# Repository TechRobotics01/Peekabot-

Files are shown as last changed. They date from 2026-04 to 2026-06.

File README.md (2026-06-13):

# Peekabot-
Peekabot is a esp32 based spy /surveillance camera system it is accessible from anywhere in the world (as long as it is connected to wifi) and it is accessed through telegram bot..

# REASON FOR BUILDING THIS 
why was this made you may ask well i previousely made a esp32 spy camera but it was based on wifi and it didn't have that long of a range also it was not battery operated and no custom pcb or any BMS so i made this and this project has all what the previous one lacked  
# LOGIC 
1. powers on 
2. searches for saved wifi
3. connects to wifi
4. connects to telegram bot via generated API key
5. bot starts
6. checks for incoming commands
7. returns output based on the input

# COMMANDS
1. "/start" to start the bot 
2. "/photo" to capture and send the image
3. "/flash on" to turn on the flash
4. "/flash off" to turn off the flash
5. "/quality" use this command followed by integres from 10-63 eg "/quality 20" (lower the number higher the quality)
8. "/autoflash on/off" to enable or disable the functionalty of tunring on flash automatically when taking a photo 
9. "/help" to get list of all the commands inside the bot's UI

# HARDWARE!
so this is a rough idea of what hardware will be used for this project!
1. Esp32 Ai-Thinker camera module
2. custom PCB base module with reset button and a usb port to power it easily 
3. 3d printed enclosure
4. 2x li-ion batteries

# PCB!!

so the pcb for the V1 of this project consists of 
1. IP5306 battery charging module 
2. micro usb connector 
3. battery connector
4.  header pins (to connect esp32 camera module)

the pcb has a samll form factor overall and will be powered by 2 li-ion battries which should give it a battery life of aproximately 8-12 hours which is enough for most applications furthermore you can just keep it plugged in via a micro usb port and keep it at a fixed place connect it to your wifi and not worry

Furthermore i will optimize the code so that the esp32 will go to deep sleep so that it could possibly in theory survive for months on a singular charge!! 

(update) the deepsleep is not implementable for this because deep sleep will result in turning off the wifi which will result in disconnection from the telegram api servers and the esp32 would not be able to wake up and it would remain in deep sleep
# SCHEMATICS






# 3D DESIGN!!
so the 3d design of this project is subdivided into 3 majour and minor parts 
1. the pcb enclosure case (3d part 1)
2. the pcb holder lid (3d part 2)
3. The battery holder (3d part 3)
4. 8x M2 2.2mm screws 

so basically the entire structure is made up of 3 parts one inside thich the pcb is mounted and then the lid of the same box 
then the battery are mounted under these 2 parts and this part is bigger and heavier than majority of the build...

Everything the pcb, the lid and the battery holder part are assembeled using M2 2.2mm screws which hold everything in place sturdily....

i tried to make the entire design as small ad i could but still it is bigger than expected however for the v1 of this build i just need a working prototype and i can impliment a better structure later on

peekabot_pcb_v1 v13
peekabot_pcb_v1 v13 PG2


## HOW TO ASSEMBLE IT ##
1. print all the parts in the 3D designs folder
2. get the pcb shipped from anywhere you can use PCBA but soldering everything yourself would be much cheaper
3. put all the SMD components for the pcb put them on the pcb with some solder paste and then put it on a hotplate and let the solder paste melt and all the smd components will be soldered in place
4. now connect 2 li-ion battery in series and solder the output wires and then add a male JST connector
5. now place the pcb in the middle piece 3d print and then screw it on using M2 allen screws
6. then connect the battery JST connector to the PCB
7. then put the esp32 camera on the PCb female header pins
8. now put all the parts together and screw it together with M2 2.2mm 10mm deep screws and refer to the exploded view.avi video for detaled instructions on where to put the screws in
9. for the software you need to log into telegram and set up a bot yourself and then you need to get the API key of the bot and then paste the API key in the code before uploading it to the camera USING AN FTDI OR BASE BASE BOARD

# EXPLODED VIEW
Screenshot_2026-04-18_185436-removebg-preview (1)

# ZINE PAGE!


# SOFTWARE USED 
1. arduino ide
2. fusion360
3. kicad
4. canava (for zine page)
5. brain.exe💀

## overall it features a small form factor as it is...afterall a spy/surveilance camera ##

# CREDITS
1. google.com
2. random nerd tutorials
3. arduino forms
4. instructuables
5. chatgpt/claude ai ONLY FOR DEBUGGING OF THE CODE

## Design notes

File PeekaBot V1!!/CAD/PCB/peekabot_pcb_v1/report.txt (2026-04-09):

Plotted to 'C:\Users\DELL\Desktop\MISSION FALLOUT\Peekabot-\PeekaBot V1!!\CAD\PCB\peekabot_pcb_v1\peekabot_pcb_v1-F_Cu.gbr'.
Plotted to 'C:\Users\DELL\Desktop\MISSION FALLOUT\Peekabot-\PeekaBot V1!!\CAD\PCB\peekabot_pcb_v1\peekabot_pcb_v1-B_Cu.gbr'.
Plotted to 'C:\Users\DELL\Desktop\MISSION FALLOUT\Peekabot-\PeekaBot V1!!\CAD\PCB\peekabot_pcb_v1\peekabot_pcb_v1-F_Paste.gbr'.
Plotted to 'C:\Users\DELL\Desktop\MISSION FALLOUT\Peekabot-\PeekaBot V1!!\CAD\PCB\peekabot_pcb_v1\peekabot_pcb_v1-B_Paste.gbr'.
Plotted to 'C:\Users\DELL\Desktop\MISSION FALLOUT\Peekabot-\PeekaBot V1!!\CAD\PCB\peekabot_pcb_v1\peekabot_pcb_v1-F_Silkscreen.gbr'.
Plotted to 'C:\Users\DELL\Desktop\MISSION FALLOUT\Peekabot-\PeekaBot V1!!\CAD\PCB\peekabot_pcb_v1\peekabot_pcb_v1-B_Silkscreen.gbr'.
Plotted to 'C:\Users\DELL\Desktop\MISSION FALLOUT\Peekabot-\PeekaBot V1!!\CAD\PCB\peekabot_pcb_v1\peekabot_pcb_v1-F_Mask.gbr'.
Plotted to 'C:\Users\DELL\Desktop\MISSION FALLOUT\Peekabot-\PeekaBot V1!!\CAD\PCB\peekabot_pcb_v1\peekabot_pcb_v1-B_Mask.gbr'.
Plotted to 'C:\Users\DELL\Desktop\MISSION FALLOUT\Peekabot-\PeekaBot V1!!\CAD\PCB\peekabot_pcb_v1\peekabot_pcb_v1-Edge_Cuts.gbr'.
Created Gerber job file 'C:\Users\DELL\Desktop\MISSION FALLOUT\Peekabot-\PeekaBot V1!!\CAD\PCB\peekabot_pcb_v1\peekabot_pcb_v1-job.gbrjob'.
Info: Done.
Info: Done.

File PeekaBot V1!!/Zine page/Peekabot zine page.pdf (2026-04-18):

## “ Capture from afar “

# Peekabot

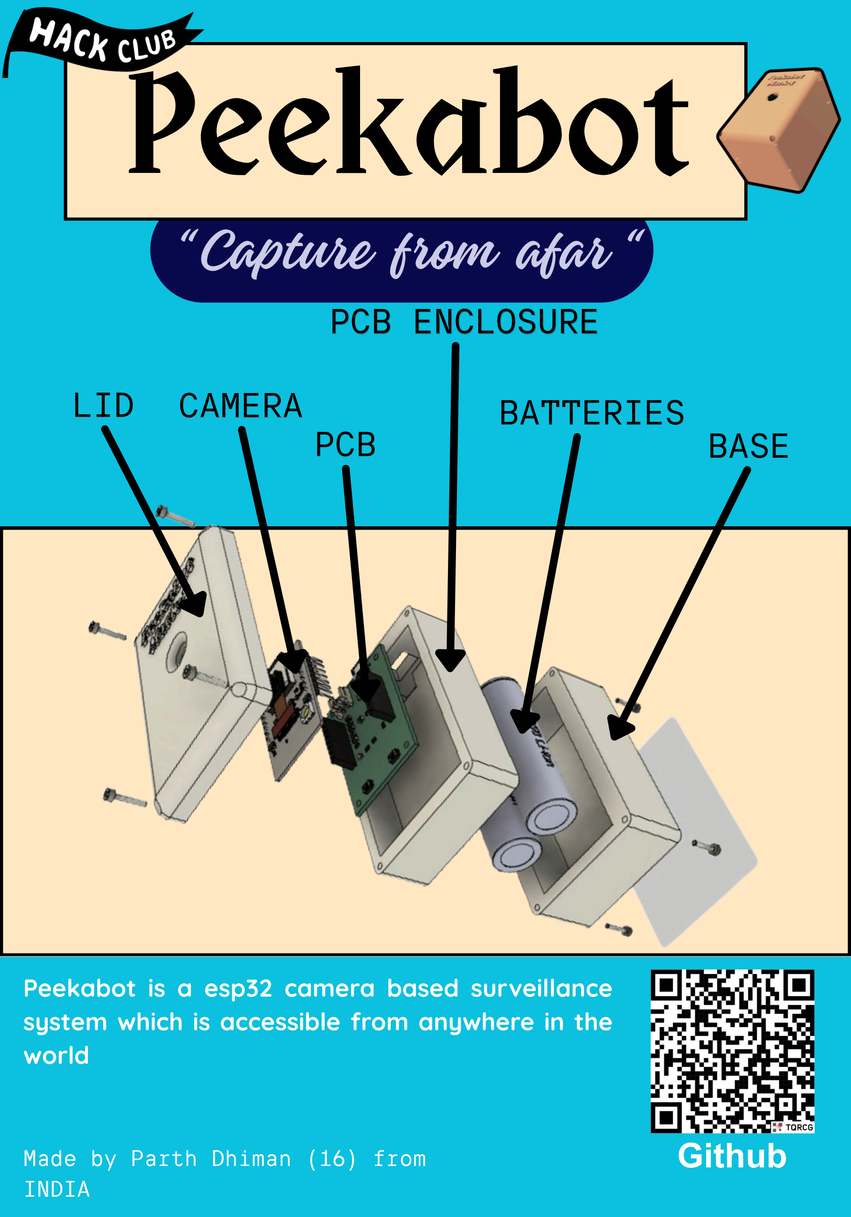
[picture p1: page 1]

## Github

## LID CAMERA PCB

## PCB ENCLOSURE

## BATTERIES BASE

Made by Parth Dhiman (16) from INDIA

Peekabot is a esp32 camera based surveillance system which is accessible from anywhere in the world

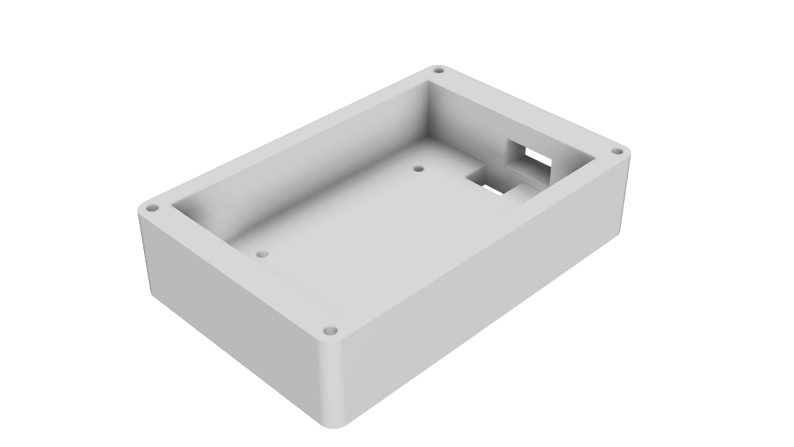
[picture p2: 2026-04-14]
PeekaBot V1!!/CAD/Renders/Peekabot 3d design part 1 v1 v21.png

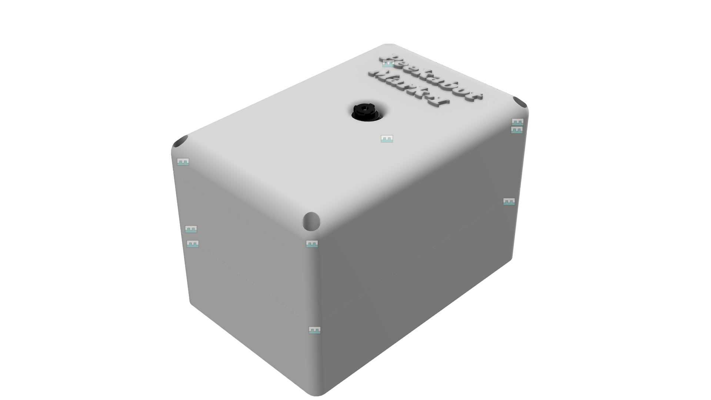
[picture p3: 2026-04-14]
PeekaBot V1!!/CAD/Renders/peekabot_pcb_v1 v13.png

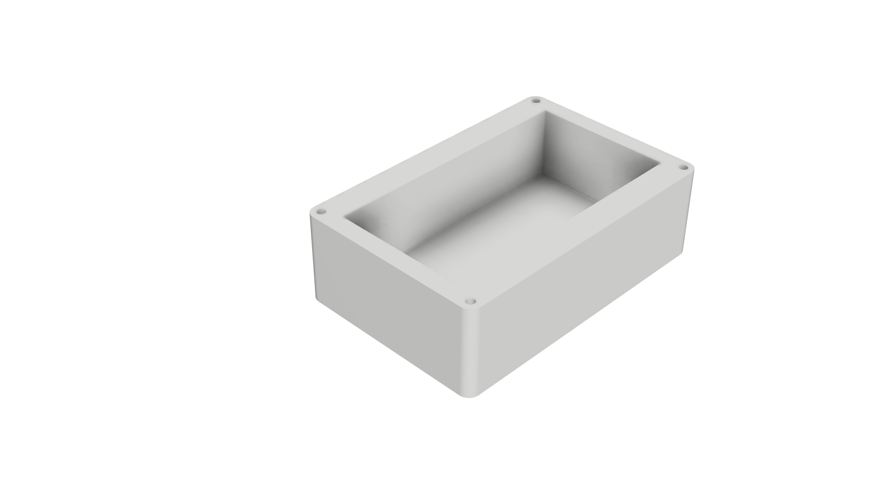
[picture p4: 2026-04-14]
PeekaBot V1!!/CAD/Renders/BATTERY HOLDER V1 v19.png

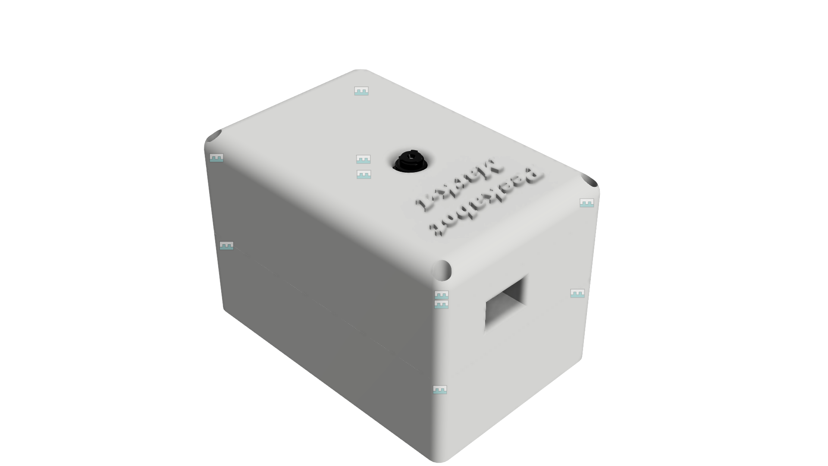
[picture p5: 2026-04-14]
PeekaBot V1!!/CAD/Renders/peekabot_pcb_v1 v13 PG2.png

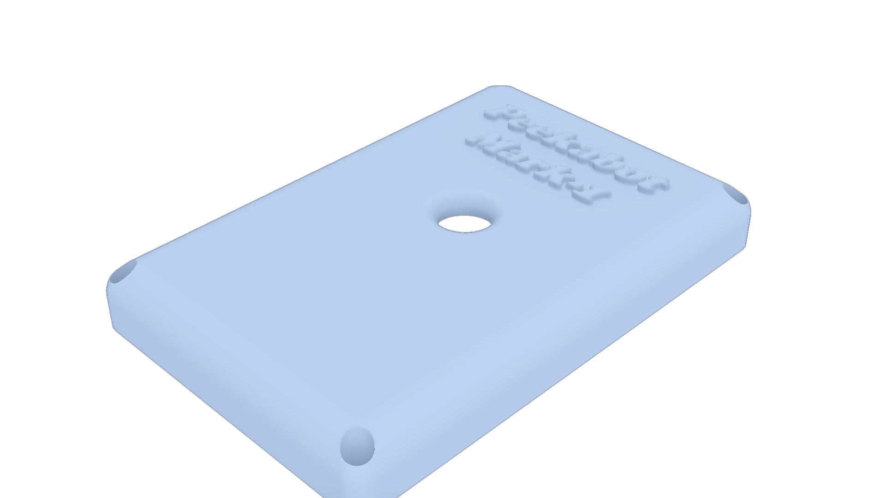
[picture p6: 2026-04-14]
PeekaBot V1!!/CAD/Renders/Peekabot lid v1 v8.png

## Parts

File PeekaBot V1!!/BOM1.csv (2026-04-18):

Index | LCSC# | Package | ESP32 | MINIMUM ORDER Quantity | quantity needed | Unit Price($) | Extended Price($) | Product Link
1 | C2930265 | 805 | 2Ω ±5% 125mW 0805 Thick Film Resistor | 100 | 1 | 0.0017 | 0.17 | https://www.lcsc.com/product-detail/C2930265.html
2 | C2907241 | 805 | 20Ω ±1% 125mW 0805 Thick Film Resistor | 100 | 1 | 0.0021 | 0.21 | https://www.lcsc.com/product-detail/C2907241.html
3 | C2907233 | 805 | 1Ω ±1% 125mW 0805 Thick Film Resistor | 100 | 1 | 0.0028 | 0.28 | https://www.lcsc.com/product-detail/C2907233.html
4 | C915305 | SMD,7.3x7.3mm | 1uH ±30% 22mΩ 7A Magnetic Shielded Inductor SMD,7.3x7.3mm Fixed Inductors RoHS | 10 | 1 | 0.1604 | 1.6 | https://www.lcsc.com/product-detail/C915305.html
5 | C72443 | SMD,4.6x2.8mm | Tactile Switch SPST 200gf 1.9mm Gull Wing 4.6mm x 2.8mm Surface Mount | 6 | 2 | 0.6234 | 3.74 | https://www.lcsc.com/product-detail/C72443.html
6 | C4987080 | 805 | 220uF ±20% 4V Tantalum Capacitors 3Ω 0805 | 1 | 1 | 3.4693 | 3.47 | https://www.lcsc.com/product-detail/C4987080.html
7 | C181692 | ESOP-8 | Lithium Battery I2C 2.1A ESOP-8 Battery Management RoHS | 5 | 1 | 0.2815 | 1.41 | https://www.lcsc.com/product-detail/C181692.html
8 |  | PCB | PCB manufacturing from lion circuits | 1 | 1 | 10.2 | 10.2 | order.lioncircuits.com
9 |  | ESP32 camera | ESP32 camera module Ai thinker | NA | NA | NA | NA | SELF-SOURCED
 |  |  |  |  |  | Total cost($) | 21.08

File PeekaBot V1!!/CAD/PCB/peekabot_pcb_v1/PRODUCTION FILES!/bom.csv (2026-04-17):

Designator | Footprint | Quantity | Value | LCSC Part #
C1, C5, C6, C7 | 805 | 4 | 10uF
C2, C3, C4 | 805 | 3 | 22uF
C8 | 805 | 1 | 110uF
C9 | 805 | 1 | 220uF
D1, D2, D3 | 805 | 3 | LED
IO0, KEY | SW_Push_1P1T_NO_CK_KMR2 | 2 | SW_Push
J1 | PinSocket_1x08_P2.54mm_Vertical | 1 | esp32camright
J2 | PinSocket_1x08_P2.54mm_Vertical | 1 | esp32camleft
J3 | USB_Micro-B_Molex-105017-0001 | 1 | USB_B_Micro
J4 | JST_EH_S2B-EH_1x02_P2.50mm_Horizontal | 1 | Battery Socket
L1 | L_7.3x7.3_H3.5 | 1 | 1uH
R1, R4 | 805 | 2 | 10KR
R2 | 805 | 1 | R
R3 | 805 | 1 | 20R
R5 | 805 | 1 | 2R
U1 | SOP127P600X165-9N | 1 | IP5306

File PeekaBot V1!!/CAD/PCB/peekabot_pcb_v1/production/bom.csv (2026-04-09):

Designator | Footprint | Quantity | Value | LCSC Part #
C1, C5, C6, C7 | 0805 | 4 | 10uF
C2, C3, C4 | 0805 | 3 | 22uF
C8 | 0805 | 1 | 110uF
C9 | 0805 | 1 | 220uF
D1, D2, D3 | 0805 | 3 | LED
IO0, KEY | SW_Push_1P1T_NO_CK_KMR2 | 2 | SW_Push
J1 | PinSocket_1x08_P2.54mm_Vertical | 1 | esp32camright
J2 | PinSocket_1x08_P2.54mm_Vertical | 1 | esp32camleft
J3 | USB_Micro-B_Molex-105017-0001 | 1 | USB_B_Micro
J4 | JST_EH_S2B-EH_1x02_P2.50mm_Horizontal | 1 | Battery Socket
L1 | L_7.3x7.3_H3.5 | 1 | 1uH
R1, R4 | 0805 | 2 | 10KR
R2 | 0805 | 1 | R
R3 | 0805 | 1 | 20R
R5 | 0805 | 1 | 2R
U1 | SOP127P600X165-9N | 1 | IP5306

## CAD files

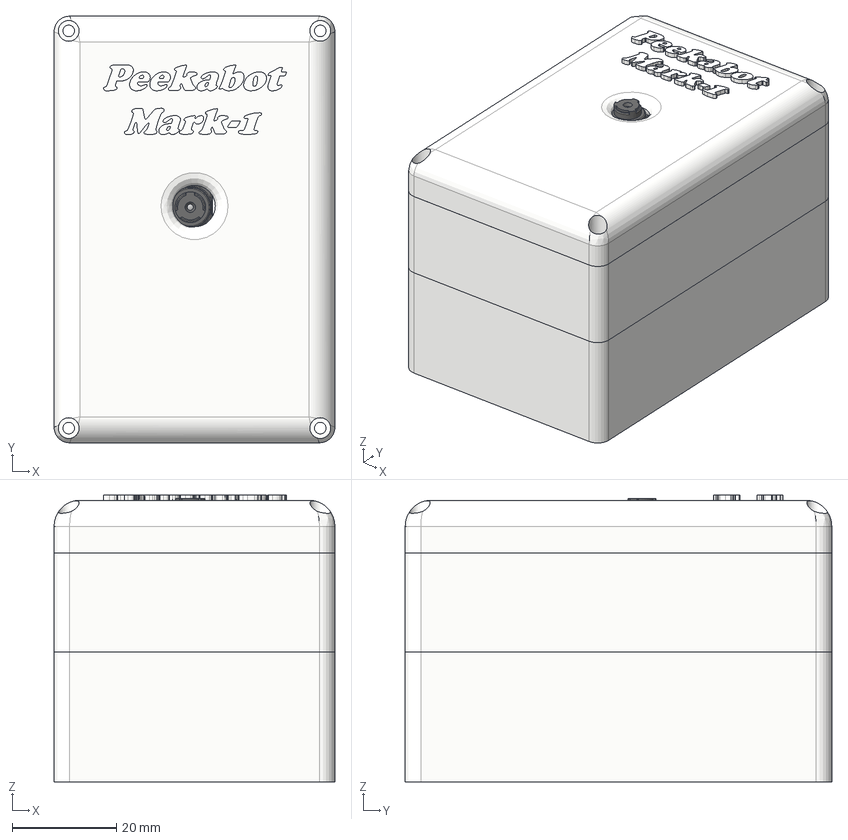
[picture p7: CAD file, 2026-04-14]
PeekaBot V1!!/CAD/3D design/Assembly stepfile/peekabot_assembly_v1 v12.step
54.0 x 82.0 x 55.1 mm
R_0805_2012Metric x 5
PinSocket_1x08_P2.54mm_Vertical x 2
LED_0805_2012Metric x 3
C_0805_2012Metric x 9
JST_EH_S2B-EH_1x02_P2.50mm_Horizontal
SW_Push_1P1T_NO_CK_KMR2 x 2
peekabot_pcb_v1_PCB
Pin Header 4 x 1 TH 2.54mm Pitch x 4
u
capacitor-CAPM-TANTB-YL
switch-3x4x2mm - 2 Pad
nano - reg
icbody
Component5(Mirror) x 4
resistor-NTC-0402-T0.6 x 20
resistor-NTC-0805-T1.3
smd-transistor-SOT23-3 x 4
LED SMD 5050 White
capacitor-CAPC-0603-T0.9-BN x 2
connector smd usl00-20l_p0-4_l12-6_w2-75
sdreader
Micro SD-Card
User Library-ov9655_ov9655_flex_pcb
User Library-ov9655_ov9655_flex_reinf
User Library-ov9655_ov9655_back_panel
User Library-ov9655_ov9655_body
User Library-ov9655_ov9655_lens
Micro USB-B Female 5Pin SMD
Peekabot 3d design part 1 v1
BATTERY HOLDER V1
Peekabot lid v1
18650 Battery x 2

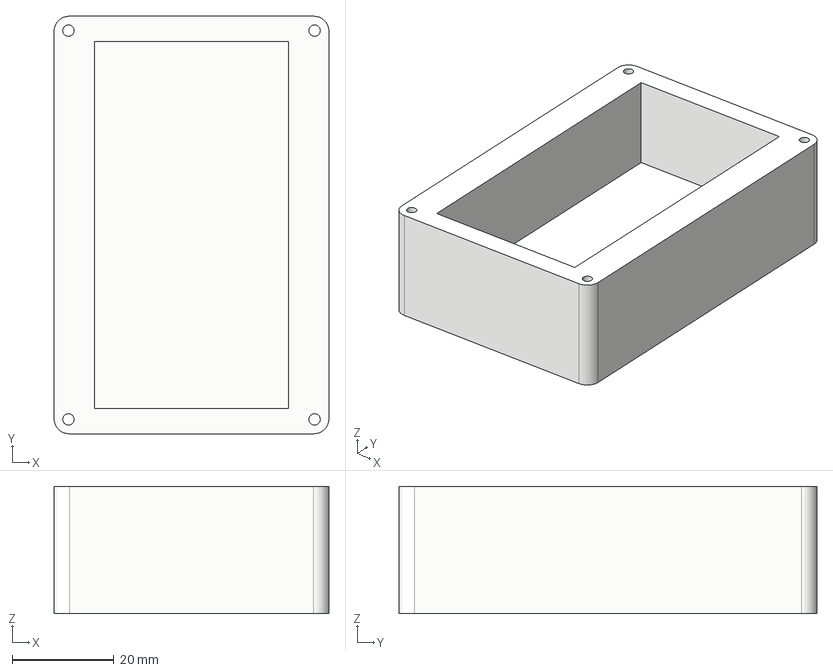
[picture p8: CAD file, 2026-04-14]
PeekaBot V1!!/CAD/3D design/3D PRINT FILES/BOTTOM PIECE/BATTERY HOLDER V1 v19.step
54.0 x 82.0 x 25.0 mm

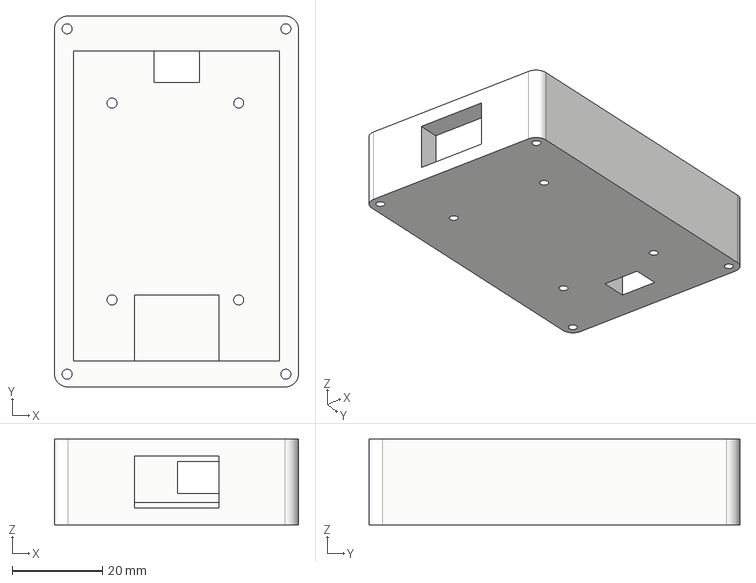
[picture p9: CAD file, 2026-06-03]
PeekaBot V1!!/CAD/3D design/3D PRINT FILES/MIDDLE PIECE/Peekabot 3d design part 1 v1 v21.step
54.0 x 82.0 x 19.0 mm

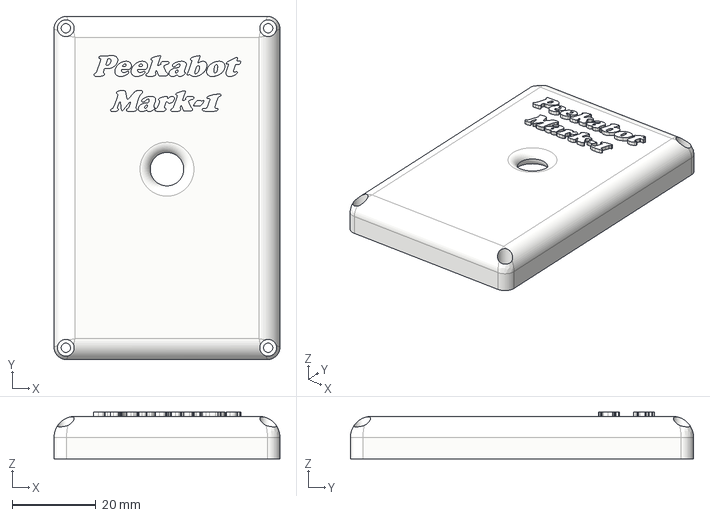
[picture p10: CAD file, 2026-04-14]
PeekaBot V1!!/CAD/3D design/3D PRINT FILES/TOP LID PIECE/Peekabot lid v1 v8.step
54.0 x 82.0 x 11.1 mm

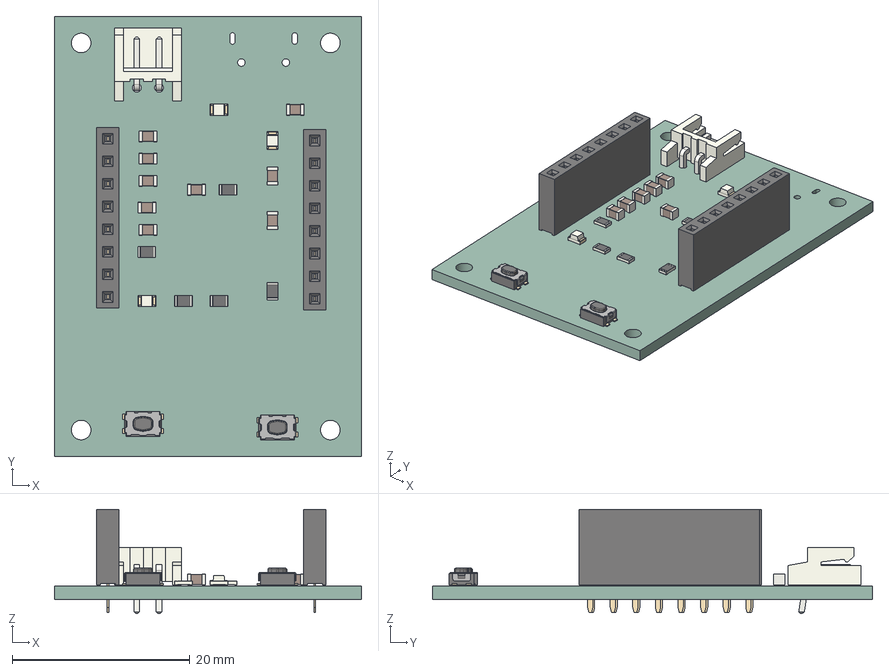
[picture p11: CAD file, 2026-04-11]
PeekaBot V1!!/CAD/3D design/pcb step file/peekabot_pcb_v1.step
34.5 x 49.5 x 11.7 mm
R_0805_2012Metric x 5
PinSocket_1x08_P2.54mm_Vertical x 2
LED_0805_2012Metric x 3
C_0805_2012Metric x 9
JST_EH_S2B-EH_1x02_P2.50mm_Horizontal
SW_Push_1P1T_NO_CK_KMR2 x 2
peekabot_pcb_v1_PCB

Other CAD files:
PeekaBot V1!!/CAD/3D design/3D PRINT FILES/BOTTOM PIECE/BATTERY HOLDER V1 v19.f3d
PeekaBot V1!!/CAD/3D design/3D PRINT FILES/MIDDLE PIECE/Peekabot 3d design part 1 v1 v21.3mf
PeekaBot V1!!/CAD/3D design/3D PRINT FILES/MIDDLE PIECE/Peekabot 3d design part 1 v1 v21.f3d
PeekaBot V1!!/CAD/3D design/3D PRINT FILES/TOP LID PIECE/Peekabot lid v1 v8.f3d

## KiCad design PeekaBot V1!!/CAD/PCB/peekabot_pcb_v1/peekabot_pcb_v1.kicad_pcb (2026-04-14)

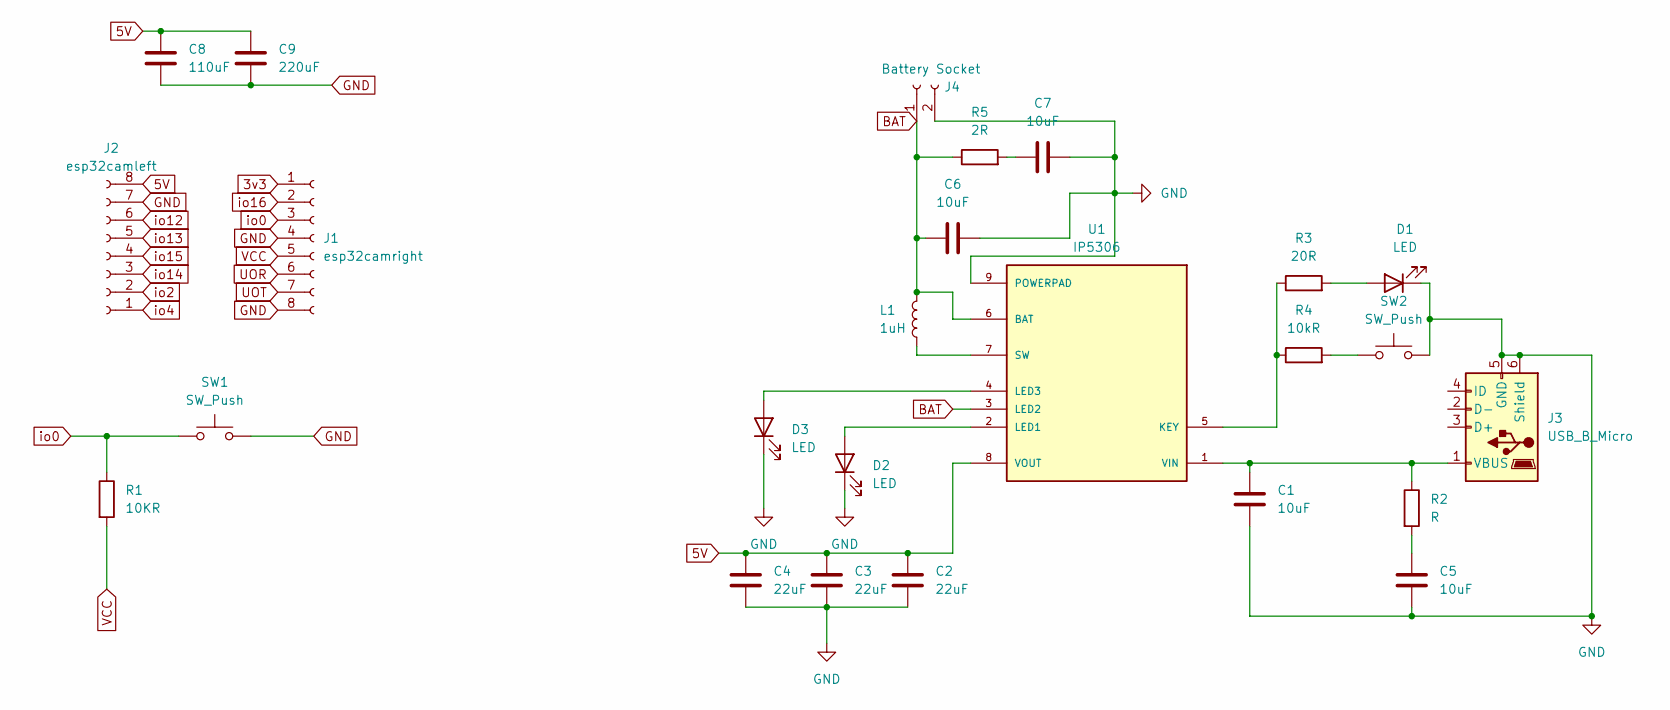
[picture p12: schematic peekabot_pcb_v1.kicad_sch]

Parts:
C1, C5, C6, C7: 10uF; C_0805_2012Metric
C2, C3, C4: 22uF; C_0805_2012Metric
C8: 110uF; C_0805_2012Metric
C9: 220uF; C_0805_2012Metric
D1, D2, D3: LED; LED_0805_2012Metric_Pad1.15x1.40mm_HandSolder
J1: esp32camright; PinSocket_1x08_P2.54mm_Vertical
J2: esp32camleft; PinSocket_1x08_P2.54mm_Vertical
J3: USB_B_Micro; USB_Micro-B_Molex-105017-0001
J4: Battery Socket; JST_EH_S2B-EH_1x02_P2.50mm_Horizontal
L1: 1uH; L_7.3x7.3_H3.5
R1: 10KR; R_0805_2012Metric
R2: R; R_0805_2012Metric
R3: 20R; R_0805_2012Metric
R4: 10kR; R_0805_2012Metric
R5: 2R; R_0805_2012Metric
SW1, SW2: SW_Push; SW_Push_1P1T_NO_CK_KMR2
U1: IP5306; SOP127P600X165-9N; PARTREV 1.31

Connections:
3v3: J1.1
5V: C2.1, C3.1, C4.1, C8.1, C9.1, J2.8, U1.8 (VOUT)
BAT: C6.1, J4.1, L1.2, R5.1, U1.3 (LED2), U1.6 (BAT)
GND: C1.2, C2.2, C3.2, C4.2, C5.2, C6.2, C7.2, C8.2, C9.2, D1.1 (K), D2.1 (K), D3.1 (K), J1.4, J1.8, J2.7, J3.5 (GND), J3.6 (Shield), J4.2, SW1.2, SW2.2, U1.9 (POWERPAD); also elsewhere on the board
unnamed: C5.1, R2.2
unnamed: C7.1, R5.2
unnamed: D1.2 (A), R3.2
unnamed: D2.2 (A), U1.2 (LED1)
unnamed: D3.2 (A), U1.4 (LED3)
unnamed: C1.1, J3.1 (VBUS), R2.1, U1.1 (VIN)
unnamed 10: R4.2, SW2.1; also elsewhere on the board
unnamed: R3.1, R4.1, U1.5 (KEY)
unnamed: L1.1, U1.7 (SW)
UOR: J1.6
UOT: J1.7
VCC: J1.5, R1.2
io0: J1.3, R1.1, SW1.1; also elsewhere on the board
io2: J2.2
io4: J2.1
io12: J2.6
io13: J2.5
io14: J2.3
io15: J2.4
io16: J1.2

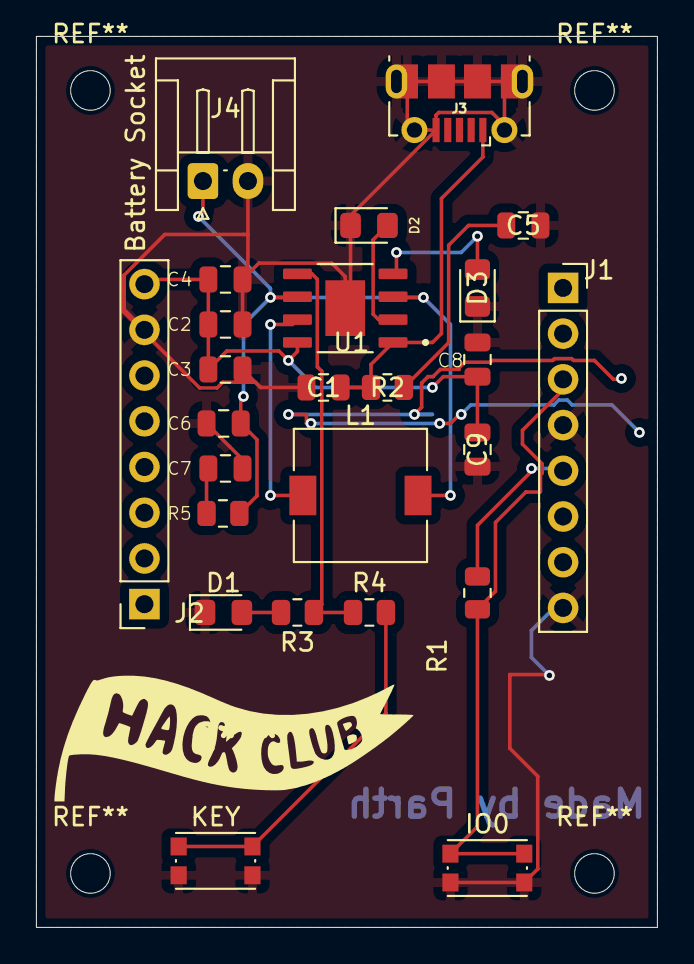
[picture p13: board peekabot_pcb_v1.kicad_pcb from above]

Board: 2 copper layers, 34.5 x 49.5 mm, 25 parts (0 on the bottom side), 14 nets.

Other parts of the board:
IO0: SW_Push; SW_Push_1P1T_NO_CK_KMR2
KEY: SW_Push; SW_Push_1P1T_NO_CK_KMR2

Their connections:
GND: IO0.2, KEY.2; also elsewhere on the board
unnamed 10: KEY.1; also elsewhere on the board
io0: IO0.1; also elsewhere on the board

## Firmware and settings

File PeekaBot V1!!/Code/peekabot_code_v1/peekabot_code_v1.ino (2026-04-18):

#include <WiFi.h>
#include <WiFiClientSecure.h>
#include <UniversalTelegramBot.h>
#include <esp_camera.h>
#include <ArduinoJson.h>

#define CAMERA_MODEL_AI_THINKER

#define PWDN_GPIO_NUM     32
#define RESET_GPIO_NUM    -1
#define XCLK_GPIO_NUM      0
#define SIOD_GPIO_NUM     26
#define SIOC_GPIO_NUM     27
#define Y9_GPIO_NUM       35
#define Y8_GPIO_NUM       34
#define Y7_GPIO_NUM       39
#define Y6_GPIO_NUM       36
#define Y5_GPIO_NUM       21
#define Y4_GPIO_NUM       19
#define Y3_GPIO_NUM       18
#define Y2_GPIO_NUM        5
#define VSYNC_GPIO_NUM    25
#define HREF_GPIO_NUM     23
#define PCLK_GPIO_NUM     22
#define LED_GPIO_NUM      4

const char* ssid = "Redmi_Note_10T_5G";
const char* password = "88888888";
const char* bottoken = "***********************"; // generate it in telegram and paste it here 

WiFiClientSecure secured_client;
UniversalTelegramBot bot(bottoken, secured_client);

const unsigned long BOT_MTBS = 1000;
unsigned long bot_lasttime;

camera_fb_t *fb = NULL;

bool isMoreDataAvailable();
byte *getNextBuffer();
int getNextBufferLen();

bool dataAvailable = false;
bool autoflash = true;

void setflash(bool state){
  digitalWrite(LED_GPIO_NUM, state ? HIGH : LOW);
}

void setquality(int quality){
  sensor_t *s = esp_camera_sensor_get();
  if(s){
    s->set_quality(s, quality);
  }
}

void handleNewMessages(int numNewMessages){
  for (int i = 0; i < numNewMessages; i++){

    String chat_id = String(bot.messages[i].chat_id);
    String text = bot.messages[i].text;

    if(text == "/photo"){

      if(autoflash){
        setflash(true);
        delay(200);
      }

      // Flush both buffered frames (fb_count=2)
      for(int j = 0; j < 2; j++){
        camera_fb_t *discard = esp_camera_fb_get();
        if(discard){
          esp_camera_fb_return(discard);
        }
      }

      // Wait for fresh frame to be captured
      delay(100);

      // Get the fresh frame
      fb = esp_camera_fb_get();

      if(autoflash){
        setflash(false);
      }

      if(!fb){
        bot.sendMessage(chat_id, "Camera capture failed", "");
        return;
      }

      dataAvailable = true;

      bot.sendPhotoByBinary(chat_id, "image/jpeg", fb->len,
                            isMoreDataAvailable, nullptr,
                            getNextBuffer, getNextBufferLen);

      esp_camera_fb_return(fb);
    }

    if (text == "/start"){
      String welcome = "Welcome to *Peekabot*\n\n";
      welcome += "Use /help to see commands";
      bot.sendMessage(chat_id, welcome, "Markdown");
    }

    if(text == "/flash on"){
      setflash(true);
      bot.sendMessage(chat_id, "Flash ON", "");
    }

    if(text == "/flash off"){
      setflash(false);
      bot.sendMessage(chat_id, "Flash OFF", "");
    }

    if(text.startsWith("/quality")){
      int q = text.substring(9).toInt();

      if(q >= 10 && q <= 63){
        setquality(q);
        bot.sendMessage(chat_id, "Quality set to " + String(q), "");
      } else {
        bot.sendMessage(chat_id, "Enter value between 10-63", "");
      }
    }

    if(text == "/autoflash on"){
      autoflash = true;
      bot.sendMessage(chat_id, "Auto Flash ON", "");
    }

    if(text == "/autoflash off"){
      autoflash = false;
      bot.sendMessage(chat_id, "Auto Flash OFF", "");
    }

    if(text == "/help"){
      String help = "*Peekabot Commands*\n\n";
      help += "/start - Start bot\n";
      help += "/photo - Take photo\n";
      help += "/flash on/off - Control flash\n";
      help += "/autoflash on/off - Auto flash control\n";
      help += "/quality X - Set quality (10-63)\n";

      bot.sendMessage(chat_id, help, "Markdown");
    }
  }
}

bool isMoreDataAvailable(){
  return dataAvailable;
}

byte *getNextBuffer(){
  dataAvailable = false;
  return fb ? fb->buf : nullptr;
}

int getNextBufferLen(){
  return fb ? fb->len : 0;
}

void setup(){
  Serial.begin(115200);

  pinMode(LED_GPIO_NUM, OUTPUT);
  digitalWrite(LED_GPIO_NUM, LOW);

  camera_config_t config;
  config.ledc_channel = LEDC_CHANNEL_0;
  config.ledc_timer = LEDC_TIMER_0;
  config.pin_d0 = Y2_GPIO_NUM;
  config.pin_d1 = Y3_GPIO_NUM;
  config.pin_d2 = Y4_GPIO_NUM;
  config.pin_d3 = Y5_GPIO_NUM;
  config.pin_d4 = Y6_GPIO_NUM;
  config.pin_d5 = Y7_GPIO_NUM;
  config.pin_d6 = Y8_GPIO_NUM;
  config.pin_d7 = Y9_GPIO_NUM;
  config.pin_xclk = XCLK_GPIO_NUM;
  config.pin_pclk = PCLK_GPIO_NUM;
  config.pin_vsync = VSYNC_GPIO_NUM;
  config.pin_href = HREF_GPIO_NUM;
  config.pin_sccb_sda = SIOD_GPIO_NUM;
  config.pin_sccb_scl = SIOC_GPIO_NUM;
  config.pin_pwdn = PWDN_GPIO_NUM;
  config.pin_reset = RESET_GPIO_NUM;
  config.xclk_freq_hz = 20000000;
  config.pixel_format = PIXFORMAT_JPEG;
  config.frame_size = FRAMESIZE_VGA;
  config.jpeg_quality = 10;
  config.fb_count = 2;

  config.grab_mode = CAMERA_GRAB_WHEN_EMPTY;

  esp_camera_init(&config);

  WiFi.begin(ssid, password);
  secured_client.setCACert(TELEGRAM_CERTIFICATE_ROOT);

  while (WiFi.status() != WL_CONNECTED){
    delay(500);
  }

  configTime(0, 0, "pool.ntp.org");

  bot.longPoll = 60;
}

void loop(){

  if (millis() - bot_lasttime > BOT_MTBS){
    int numNewMessages = bot.getUpdates(bot.last_message_received + 1);

    while (numNewMessages){
      handleNewMessages(numNewMessages);
      numNewMessages = bot.getUpdates(bot.last_message_received + 1);
    }

    bot_lasttime = millis();
  }
}

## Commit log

2026-04-05 Developed code for Peekabot camera
2026-04-06 STARTED WORK ON THE PCB SCHEMATICS FOR THE BASEBOARD OF ESP32
    [peekabot_pcb_v1.kicad_pcb, peekabot_pcb_v1.kicad_sch]
2026-04-08 started working on the schematics of the pcb
    [peekabot_pcb_v1.kicad_pcb, peekabot_pcb_v1.kicad_sch]
2026-04-09 UPDATED PCB-MARK-1!!!
    [bom.csv, designators.csv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]
2026-04-11 PCB AND 3D DESIGN WORK
    started 3d printable enclosure design for the project and corrected a majour spacing error in the PCB
    [bom.csv, designators.csv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]
2026-04-12 updated 3d enclosure files
    [BATTERY HOLDER V1 v13.step]
2026-04-14 UPDATED AND IMPROVED CODE
    [BATTERY HOLDER V1 v13.3mf, Peekabot 3d design part 1 v1 v15.3mf, Peekabot 3d design part 1 v1 v15.step]
2026-04-14 Upodated code,3d desig,pcb
    improved the code
    improved and iterated the 3d design
    rendered all the 3d parts
    added name and hack club logo in the pcb
    organized all the file
    [BATTERY HOLDER V1 v13.3mf, BATTERY HOLDER V1 v13.step, BATTERY HOLDER V1 v19.step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]
2026-04-15 Created BOM
    [BOM V1.csv]
2026-04-17 FINALIZED BOM
    [bom.csv, designators.csv, positions.csv]
2026-04-18 created zine page and updated BOM
    [BOM V1.csv, BOM V2.csv]
2026-04-18 updated zine,bom,code
2026-04-23 added more cad files
    [BATTERY HOLDER V1 v19.f3d, Peekabot 3d design part 1 v1 v21.f3d, Peekabot lid v1 v8.f3d]
2026-04-23 update name of bom file
    [BOM.csv]
2026-06-01 updated bom and cad stuff
    [BOM1.csv, Peekabot 3d design part 1 v1 v21.step, bom.csv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]
2026-06-03 peekabot updates
    [Peekabot 3d design part 1 v1 v21.3mf, Peekabot 3d design part 1 v1 v21.f3d, Peekabot 3d design part 1 v1 v21.step]
